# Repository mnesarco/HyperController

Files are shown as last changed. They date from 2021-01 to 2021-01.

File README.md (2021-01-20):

# HyperController

Arduino based device for 3D space navigation and manipulation inside FreeCAD and probably others.

This stated as a weekend project for my own usage, but the outcome was so satisfiying so 
I am releasing it as Open Hardware with love to the FreeCAD Community.

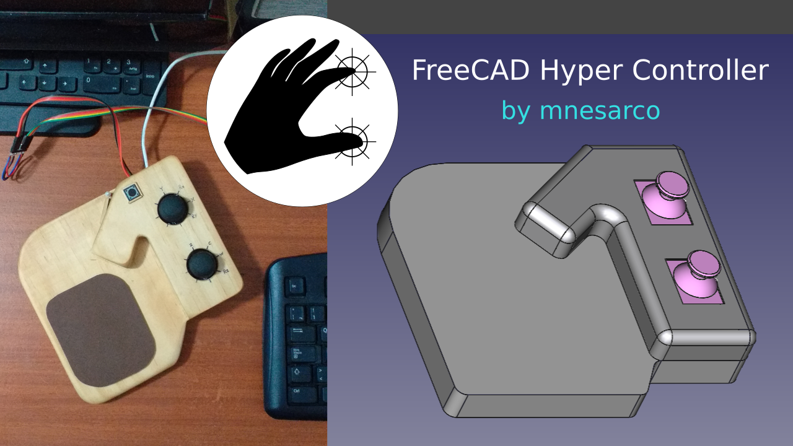
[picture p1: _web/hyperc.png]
(https://www.youtube.com/watch?v=o9VPcpPox0Q)

[View on youtube.com](https://www.youtube.com/watch?v=o9VPcpPox0Q)

## Project Status

This project is in its infancy, currently it is just the result of a weekend project.

## IMPORTANT!!!

This repository is not a FreeCAD extension, this repo contains the Hardware and Firmware part of the HyperController. The required FreeCAD extension is [Mnesarco Utils](https://github.com/mnesarco/FreeCAD_Utils), you must install it from: https://github.com/mnesarco/FreeCAD_Utils

## Features/Goals

* Keep the hand in rest position all the time
* Allow direct Panning, Zomming and Rotation without modal buttons and without Mouse or Keyboard interference.
* Extendable Hardware, Firmware and Software
* Open Hardware, Open Source
* USB communication
* Affordable components
* Easy to build, easy to install, easy to mod

## Documentation

* Arduino Wiring/Schematic:
https://github.com/mnesarco/HyperController/raw/main/hardware/schema.pdf
* Axes Movements: https://github.com/mnesarco/HyperController/raw/main/hardware/axes.pdf
* Firmware: The source code is well documented: https://github.com/mnesarco/HyperController/blob/main/firmware
  * `config.hpp` contains all configurations.
  * `HyperController.ino` is the main arduino sketch.
  * Everything else are utilities.

## FreeCAD Integration

This device uses USB to comunicate with FreeCAD, in order to make it happend, you need to Install a FreeCAD extension called "Mnesarco's Utils for FreeCAD" from here: https://github.com/mnesarco/FreeCAD_Utils.git

## License and permissions

1. Freely Use and/or modify this software under GPLv3. So if you use and/or modify it, please share your modifications back to the community.
2. It is not allowed to use or distribute this software/hardware commercially or with commercial purposes. I you want a commercial license, please contact me.
3. If you redistribute this project or any of its parts, you must include a copyright notice: **Copyright (c) 2020 Frank D. Martinez M.** and a link to this repository: https://github.com/mnesarco/HyperController.git
4. You must not modify the copyright info inside the source files.

## Forum threads

* https://forum.freecadweb.org/viewtopic.php?f=24&t=54367

## Important notes about files inside **hardware/3dmodel**

Files inside `hardware/3dmodel` requires:
* FreeCAD 0.19_pre+
* Assembly4 Workbench (https://github.com/Zolko-123/FreeCAD_Assembly4)
* Mnesarco Utils Extension Pack (https://github.com/mnesarco/FreeCAD_Utils)

## Parts

|Image |Description  |Optional
|---|---|---
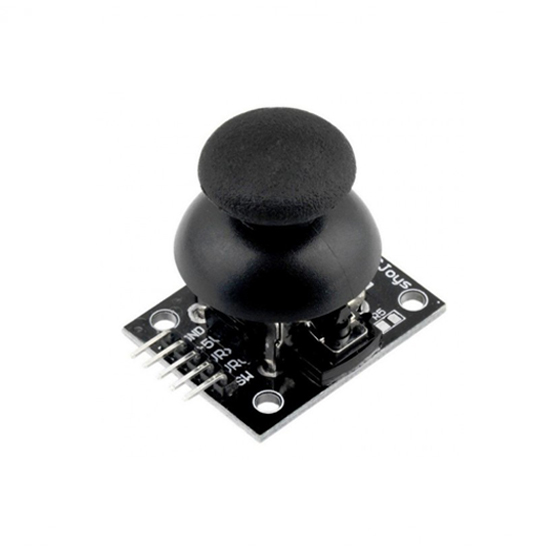
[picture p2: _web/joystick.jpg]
||2 Joystick modules|
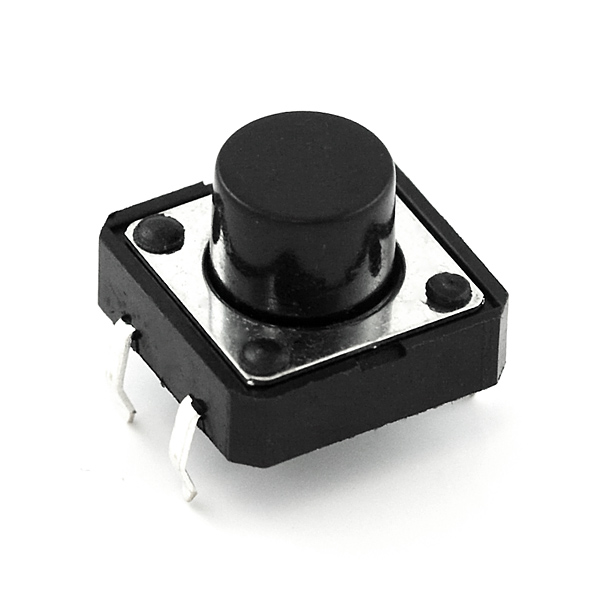
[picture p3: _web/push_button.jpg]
||1-3 Push buttons|
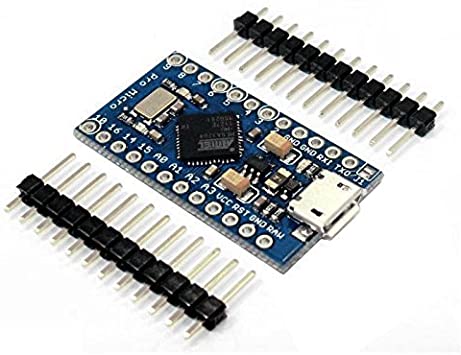
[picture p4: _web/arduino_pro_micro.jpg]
||1 Arduino Pro Micro|
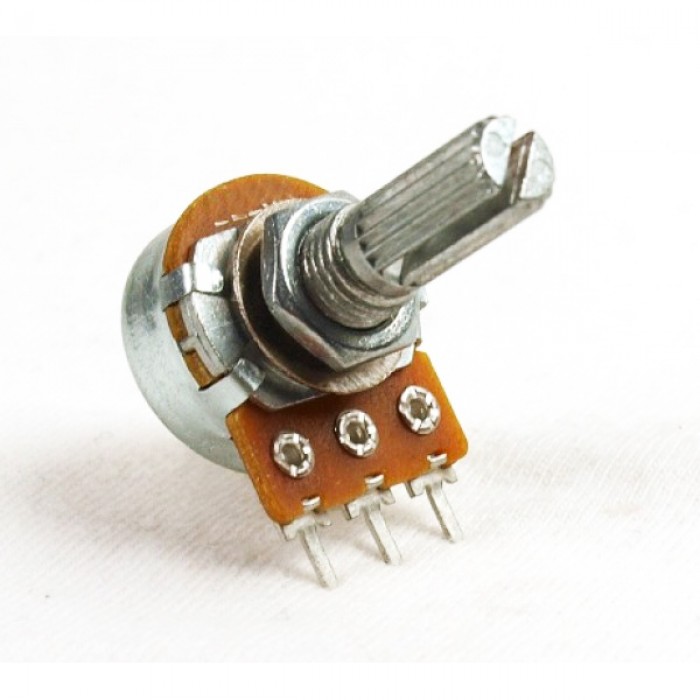
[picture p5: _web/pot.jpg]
||0-3 Potentiometers (Value: between 10k and 50k are ok)|Optional

## Notices

* ARDUINO&reg; and other Arduino brands and logos are Trademarks of Arduino SA.
* FreeCAD is an independent Open Source project: https://freecadweb.org

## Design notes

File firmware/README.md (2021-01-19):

# HyperController Firmware

This directory contains the Arduino Sketch and its dependencies.

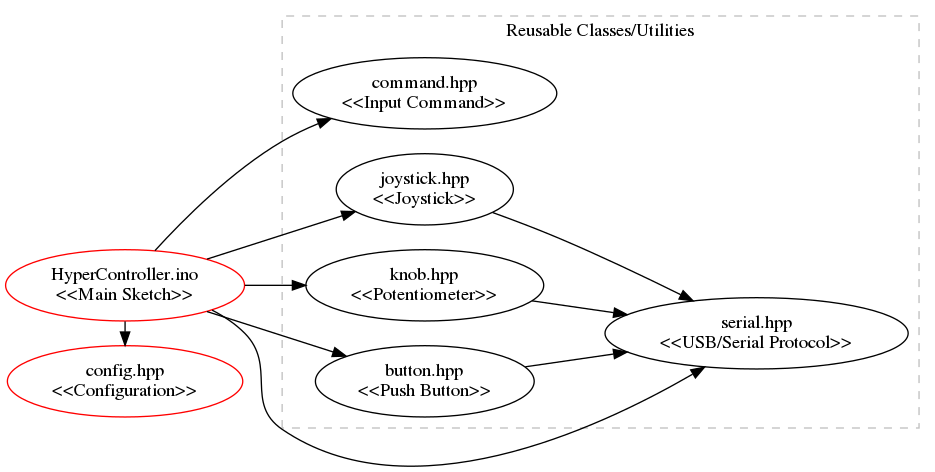
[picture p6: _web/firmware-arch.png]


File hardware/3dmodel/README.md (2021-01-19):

## 3D Model

This directory contains a FreeCAD file: `base1.FCStd` which is an enclosure prototype. It was created with **FreeCAD 0.19_pre+**, **Assembly4**, and **Mnesarco Utils**, so in order to open it, you need to have those installed.

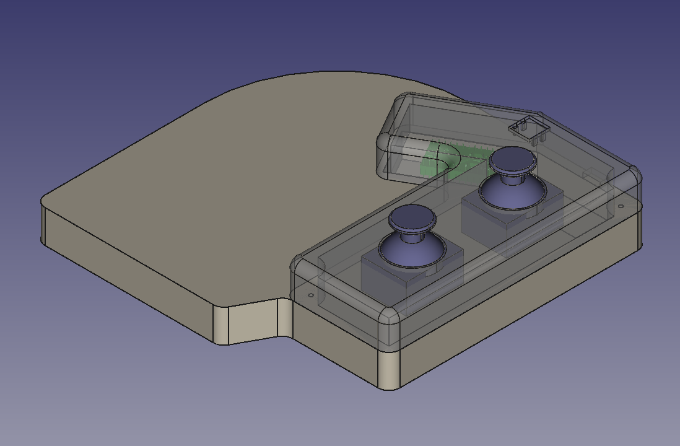
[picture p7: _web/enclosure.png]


There is also a script file: `vars.py` which contains main parameters of the enclosure, it must be in the same directory of `base1.FCStd`, so if you download `base1.FCStd` remember to download also `vars.py` and put both in the same directory.

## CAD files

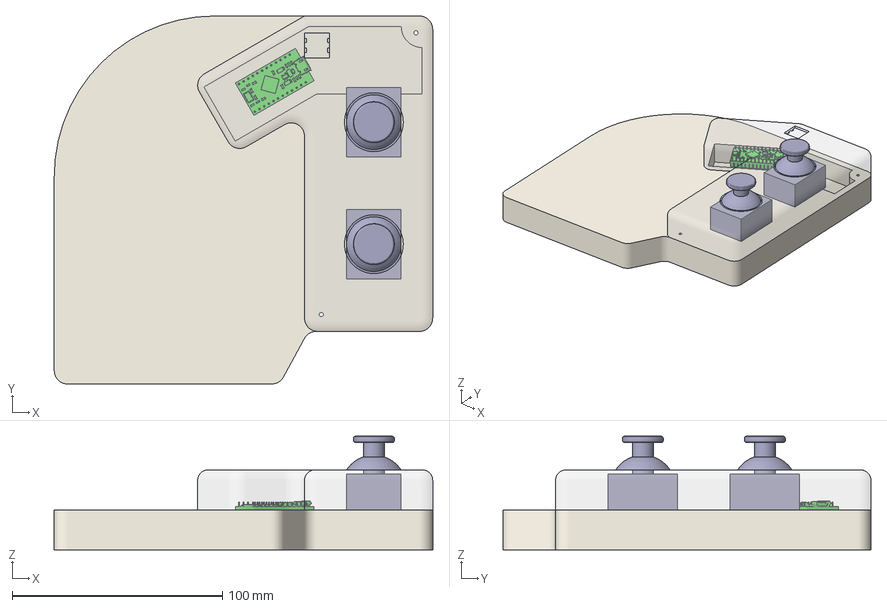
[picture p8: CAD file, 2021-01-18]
hardware/3dmodel/base1.FCStd
180.0 x 175.0 x 54.0 mm
BasePlate
TopPlate
Joystick x 2
Arduino_Pro_Micro_Header

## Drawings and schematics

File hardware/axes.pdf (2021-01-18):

## HyperController Axes

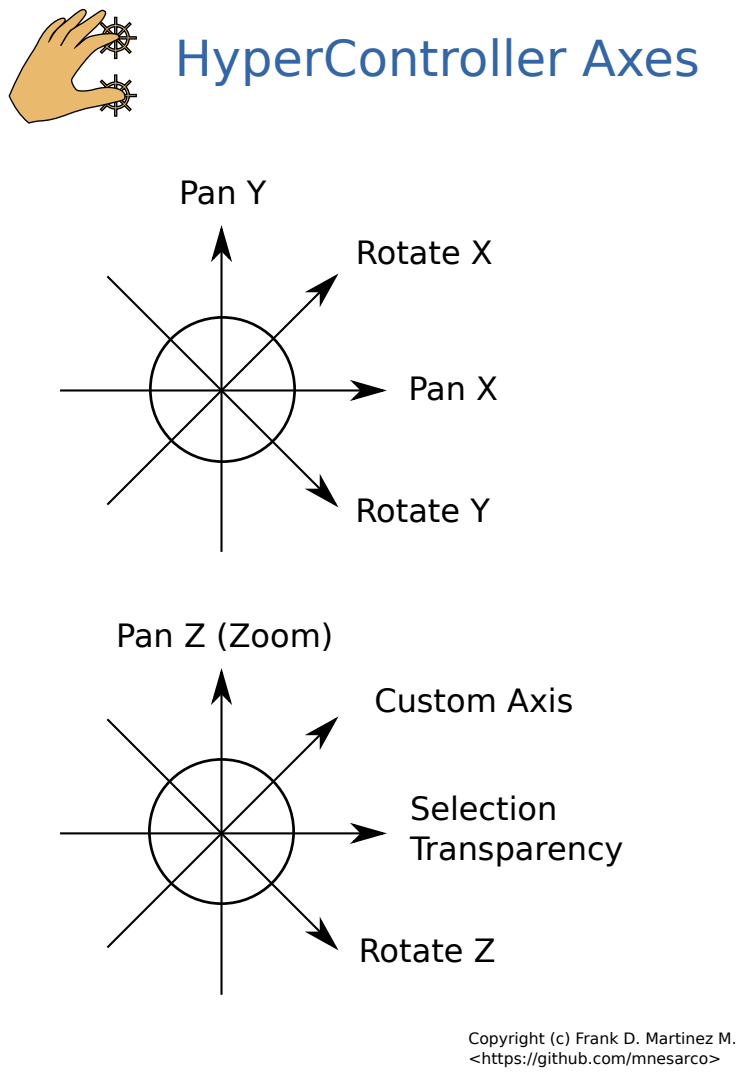
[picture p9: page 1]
Pan Y; Pan X; Rotate X; Rotate Y; Pan Z (Zoom); Selection Transparency; Rotate Z; Custom Axis

Copyright (c) Frank D. Martinez M.
<https://github.com/mnesarco>

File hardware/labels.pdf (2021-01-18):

# HyperController

# Joystick labels

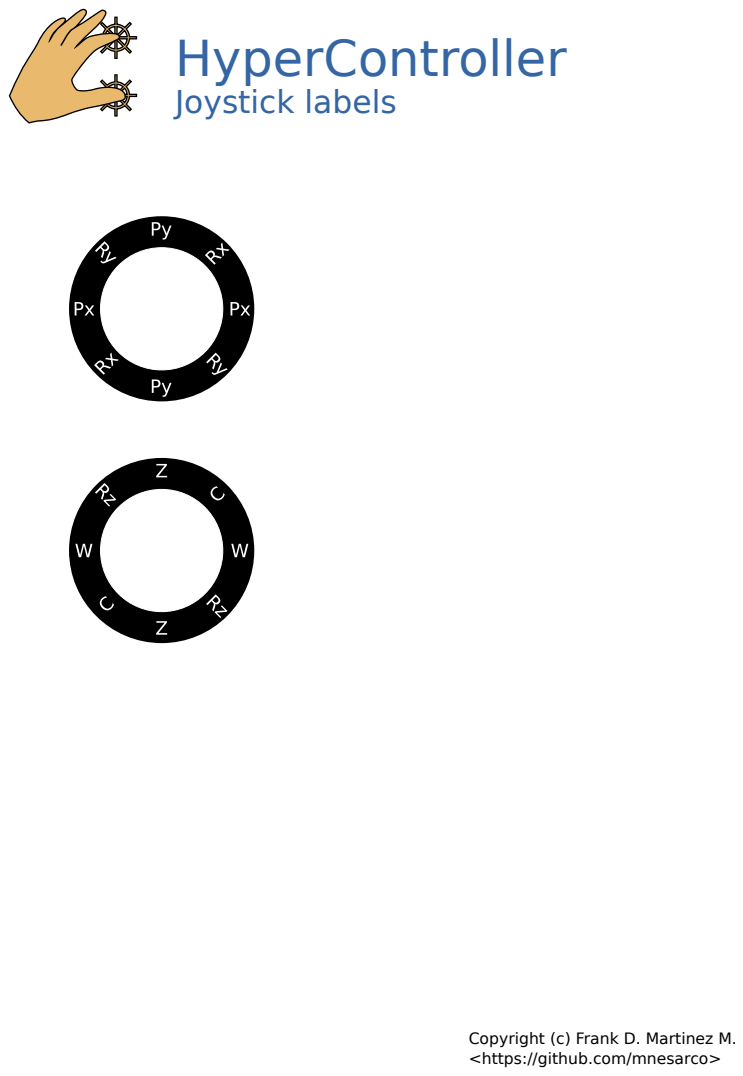
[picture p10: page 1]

Copyright (c) Frank D. Martinez M.
<https://github.com/mnesarco>

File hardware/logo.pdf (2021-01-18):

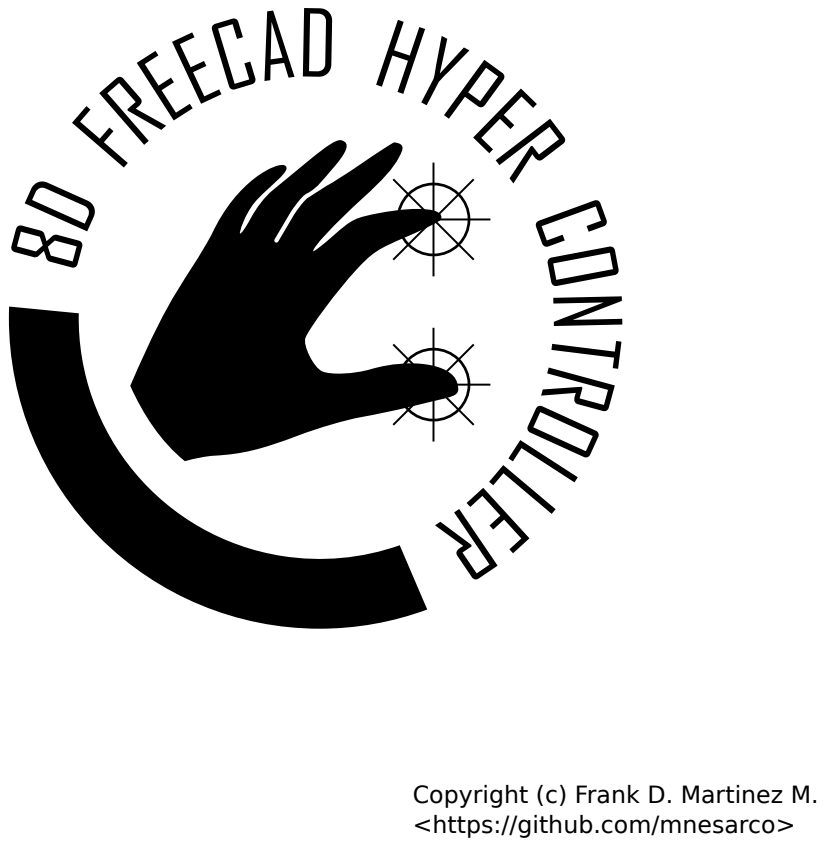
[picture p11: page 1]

Copyright (c) Frank D. Martinez M.
<https://github.com/mnesarco>

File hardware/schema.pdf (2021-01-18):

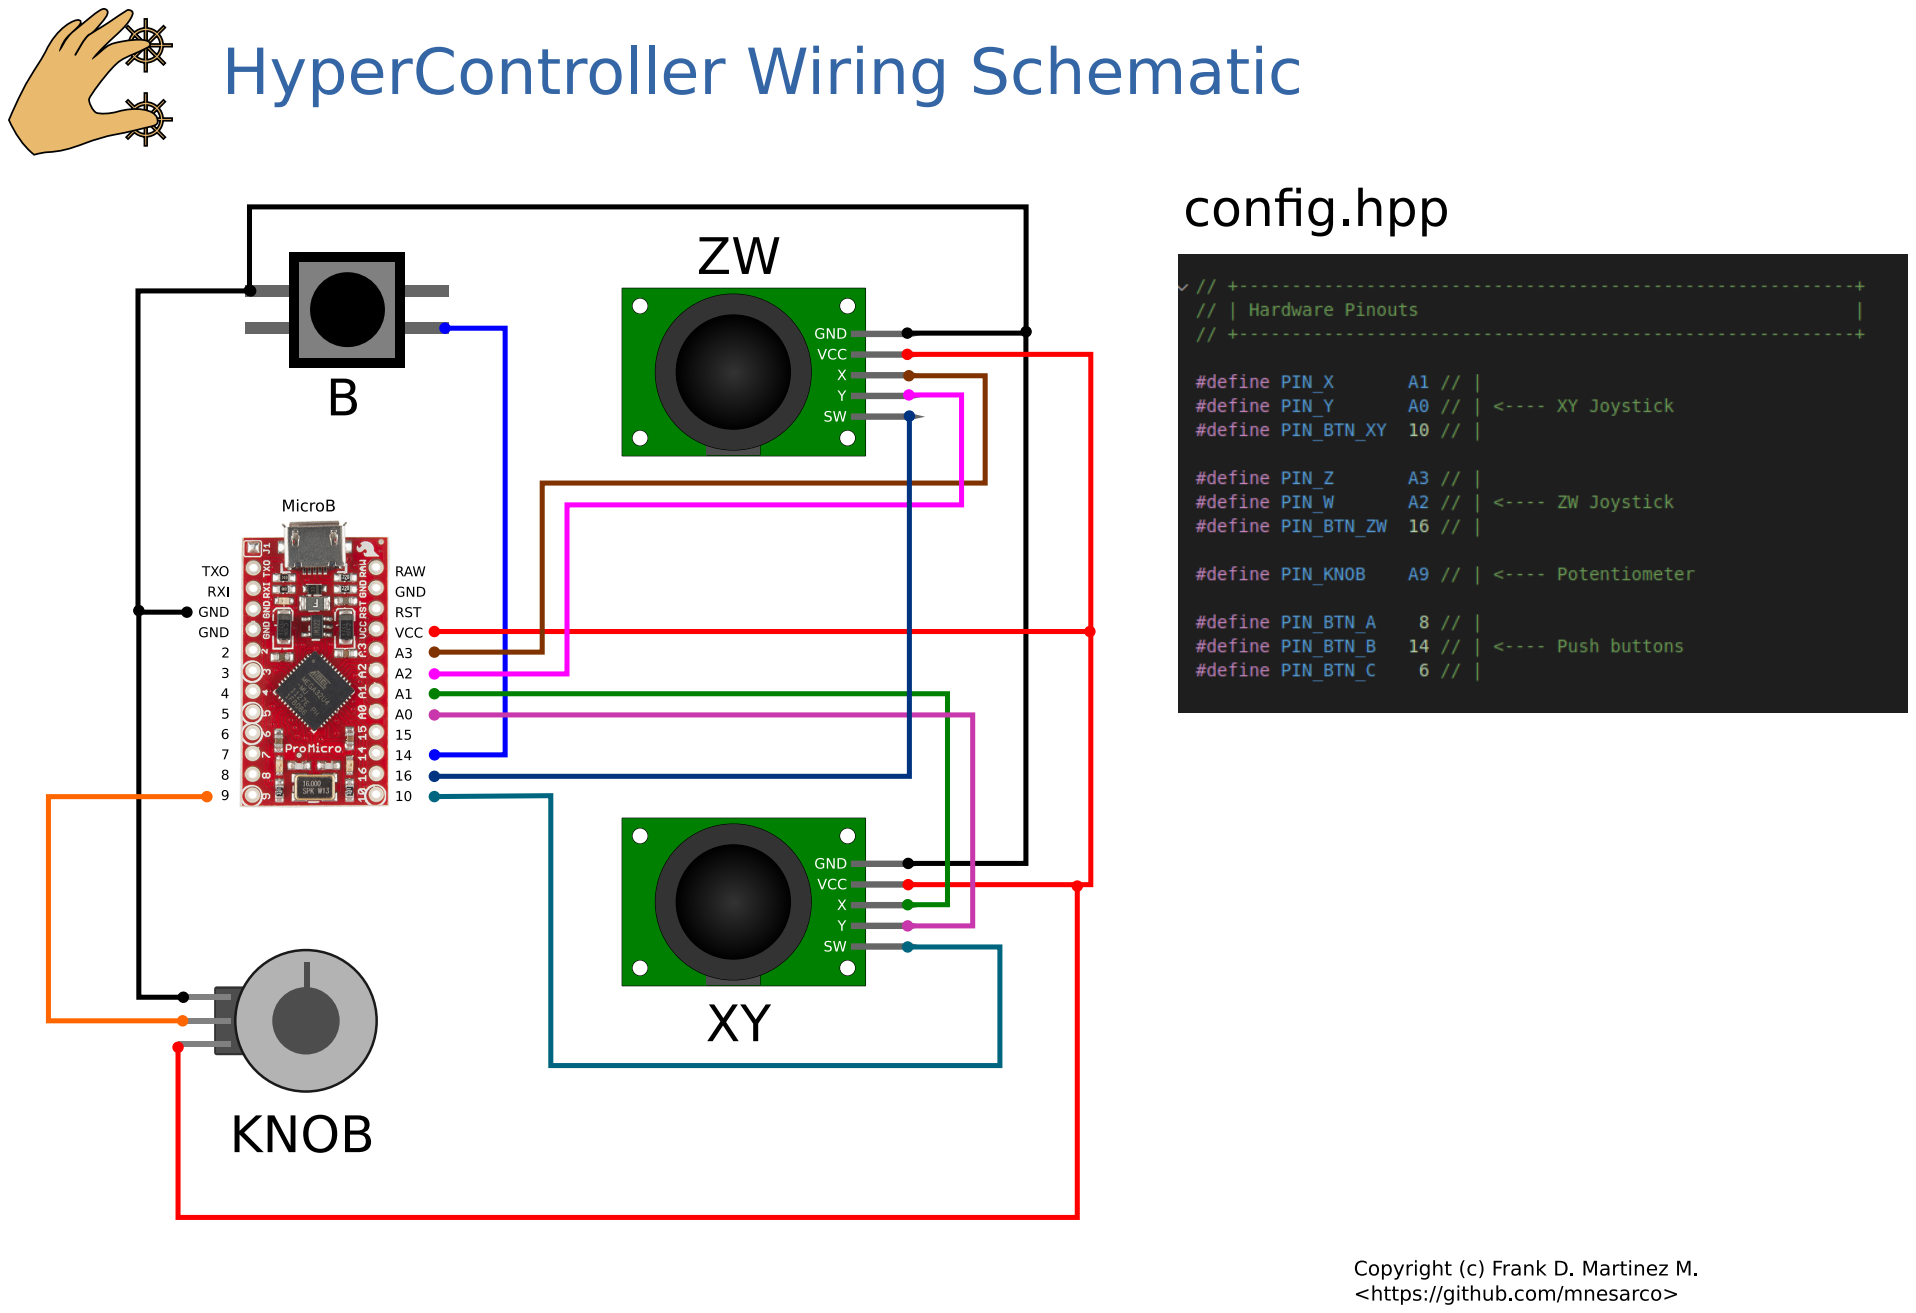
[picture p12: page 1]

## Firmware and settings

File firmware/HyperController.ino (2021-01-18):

// Copyright (C) 2021 Frank David Martinez M. <https://github.com/mnesarco/>
// 
// This file is part of HyperController.
// 
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

#include "config.hpp"
#include "button.hpp"
#include "serial.hpp"
#include "joystick.hpp"
#include "knob.hpp"
#include "command.hpp"

// +--------------------------------------------------------------------------+
// | Global state                                                             |
// +--------------------------------------------------------------------------+

// Buttons
Button<PIN_BTN_XY, EVENT_BUTTON_XY_CLICK, EVENT_BUTTON_XY_LONG_PRESS> button_xy;
Button<PIN_BTN_ZW, EVENT_BUTTON_ZW_CLICK, EVENT_BUTTON_ZW_LONG_PRESS> button_zw;
Button<PIN_BTN_A,  EVENT_BUTTON_A_CLICK,  EVENT_BUTTON_A_LONG_PRESS>  button_a;
Button<PIN_BTN_B,  EVENT_BUTTON_B_CLICK,  EVENT_BUTTON_B_LONG_PRESS>  button_b;
Button<PIN_BTN_C,  EVENT_BUTTON_C_CLICK,  EVENT_BUTTON_C_LONG_PRESS>  button_c;

// Joysticks
Joystick<PIN_X, PIN_Y, EVENT_X, EVENT_Y, EVENT_RX, EVENT_RY, EVENT_XY0, JOYSTICK_THRESHOLD, SENSITIVITY> jxy;
Joystick<PIN_W, PIN_Z, EVENT_W, EVENT_Z, EVENT_RW, EVENT_RZ, EVENT_ZW0, JOYSTICK_THRESHOLD, SENSITIVITY> jzw;

// Knobs
Knob<PIN_KNOB, EVENT_KNOB, KNOB_THRESHOLD> knob;

// setup completion
bool ready = false;


// +--------------------------------------------------------------------------+
// | Commands                                                                 |
// |   functions that respond to command codes received by usb                |
// +--------------------------------------------------------------------------+

void cmd_print_info()
{
  send(EVENT_COMMENT, F(FIRMWARE_NAME " version " FIRMWARE_VERSION));
  send(EVENT_COMMENT, F(FIRMWARE_COPYRIGHT));
  send(EVENT_COMMENT, F("Compilation: " __DATE__ " " __TIME__));
};

void cmd_recalibrate()
{
  knob.calibrate();
  jxy.calibrate();
  jzw.calibrate();
  send(EVENT_COMMENT, F("Recalibration completed"));
};


// +==========================================================================+
// || Arduino::Setup                                                         ||
// +==========================================================================+

void setup()
{
  
  // Serial port
  serial_init();

  // Controls
  jxy.init();
  jzw.init();
  knob.init();
  button_xy.init();
  button_zw.init();
  button_a.init();
  button_b.init();
  button_c.init();

  cmd_print_info();
  ready = true;

}


// +==========================================================================+
// || Arduino::Loop                                                          ||
// +==========================================================================+

void loop()
{

  // wait for setup completion
  if (!ready) {
    return;
  }

  // Currrent time
  unsigned long time = millis();

  // Process serial inputs
  process_commands {
    command(CMD_FIRMWARE_INFO, cmd_print_info);
    command(CMD_CALIBRATE, cmd_recalibrate);
  }

  // Process serial outputs
  jxy.process();  
  jzw.process();
  knob.process();
  button_xy.process(time);
  button_zw.process(time);
  button_a.process(time);
  button_b.process(time);
  button_c.process(time);

  // Show version info if requested by hardware
  if (button_xy.long_pressed && button_zw.long_pressed)
  {
    cmd_print_info();
  }

  // Slowdown
  delay(SLOWDOWN);

}

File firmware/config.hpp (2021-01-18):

// Copyright (C) 2021 Frank David Martinez M. <https://github.com/mnesarco/>
// 
// This file is part of HyperController.
// 
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

#ifndef MNESARCO_3DM_CONFIG_H
#define MNESARCO_3DM_CONFIG_H

// +----------------------------------------------------------+
// | Firmware Identification                                  |
// +----------------------------------------------------------+

#define FIRMWARE_NAME       "Mnesarco's Hyper Controller Firmware"
#define FIRMWARE_VERSION    "1.0.0"
#define FIRMWARE_COPYRIGHT  "Copyright (C) 2021 Frank D. Martinez M. <https://github.com/mnesarco>"
#define FIRMWARE_LICENSE    "GPLv3 <https://www.gnu.org/licenses/gpl-3.0.en.html>"


// +----------------------------------------------------------+
// | Hardware Pinouts                                         |
// +----------------------------------------------------------+

#define PIN_X       A1 // |
#define PIN_Y       A0 // | <---- XY Joystick
#define PIN_BTN_XY  10 // |

#define PIN_Z       A3 // |  
#define PIN_W       A2 // | <---- ZW Joystick
#define PIN_BTN_ZW  16 // | 

#define PIN_KNOB    A9 // | <---- Potentiometer

#define PIN_BTN_A    8 // |
#define PIN_BTN_B   14 // | <---- Push buttons
#define PIN_BTN_C    6 // |


// +----------------------------------------------------------+
// | Calibration parameters                                   |
// +----------------------------------------------------------+

#define BUTTON_LONG_PRESS_TIME  500  // Pressed milliseconds to trigger Long Press event
#define BUTTON_CLICK_TIME        80  // Pressed milliseconds to trigger Click event
#define SENSITIVITY             100  // Higher sensitivity value = slower mouse, should be <= about 500
#define SLOWDOWN                 30  // Main loop slowdown (ms)
#define JOYSTICK_THRESHOLD        5  // To avoid oscillations near to center
#define KNOB_THRESHOLD            5  // To avoid oscillations


// +----------------------------------------------------------+
// | Event codes (sent through usb)                           |
// +----------------------------------------------------------+

#define EVENT_X                       1 // |
#define EVENT_Y                       2 // | <--- Orthogonal Axes events
#define EVENT_Z                       3 // |      (translational axes)
#define EVENT_W                       4 // |

#define EVENT_RX                      5 // |
#define EVENT_RY                      6 // | <--- 45 deg Axes events
#define EVENT_RZ                      7 // |      (rotational axes)
#define EVENT_RW                      8 // |

#define EVENT_XY0                     9 // | <--- Joystick center events
#define EVENT_ZW0                    10 // | 

#define EVENT_BUTTON_XY_CLICK        50 // | <--- XY Joystick push button events
#define EVENT_BUTTON_XY_LONG_PRESS   51 // | 

#define EVENT_BUTTON_ZW_CLICK        60 // | <--- ZW Joystick push button events
#define EVENT_BUTTON_ZW_LONG_PRESS   61 // | 

#define EVENT_BUTTON_A_CLICK         70 // |
#define EVENT_BUTTON_A_LONG_PRESS    71 // |
                                        // | 
#define EVENT_BUTTON_B_CLICK         80 // | <--- Push buttons events
#define EVENT_BUTTON_B_LONG_PRESS    81 // |
                                        // |
#define EVENT_BUTTON_C_CLICK         90 // |
#define EVENT_BUTTON_C_LONG_PRESS    91 // |

#define EVENT_KNOB                  100 // | <--- Knob (potentiometer) event

#define EVENT_COMMENT               999 // | <--- Generic text based event


// +----------------------------------------------------------+
// | Commands (received through usb)                          |
// +----------------------------------------------------------+

#define CMD_FIRMWARE_INFO  1  // Print Firmware version
#define CMD_CALIBRATE      2  // Recalibrate Analogs (all analogs should be physically in zero position)


// +----------------------------------------------------------+
// | USB Communication                                        |
// +----------------------------------------------------------+

#define BAUD_RATE  115200  // Serial port speed

#endif

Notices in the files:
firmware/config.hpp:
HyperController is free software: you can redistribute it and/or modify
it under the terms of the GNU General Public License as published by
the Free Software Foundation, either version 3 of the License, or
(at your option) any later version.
